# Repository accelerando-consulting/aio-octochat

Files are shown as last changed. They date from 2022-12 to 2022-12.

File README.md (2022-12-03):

# OctoChat - a tileable foot keyboard for people or pets

This project is a circuit board that allows one to construct a mechanical keyboard
as large or as small as you like.   From a single key, to potentially 64 keys.

The keyboard connects via I2C - it can connect direct to a raspberry pi, or to a small
microcontroller.   ESP32, ESP8266 and Nordic NRF52 are good choices.  

If you have a board that runs circuitpython such as the Adafruit feather or one of Accelerando's
Redsoil or Hailstone boards you can create a USB or Bluetooth keyboard with the included CircuitPython code.

Accelerando's Stacx project (for the Ardiuino framework) also supports these keys.

## How it works

The PCF8574 IO expander is used.   This chip has 8 pins, each key uses two pins.    A four key board can be made with
one octochat fitted with a PCF8574 and three more octochats *with no chip*.   Each active octochat can control three other passive octochats.   Connections can be chained, so you can add another active octochat into your board.   The PCF8574 supports 16 addresses, so you can have up to 16 active keys, plus up to 48 passive keys.

Each key has one keyswith and one LED.  Program the IO Expander's register with bit pattern 0xFF.   When a key is pressed, that bit will read zero.   To light a LED, program the corresponding bit to a zero.

The outputs of the PCF8574 are arranged thusly

 * D0 - the key on this module (pulled high, low when pressed)
 * D1 - the LED on this module (sink mode, program output low to light the LED)
 * D2 - the key on passive module 2
 * D3 - the LED on passive module 2
 * D4 - the key on passive module 3
 * D5 - the LED on passive module 3
 * D6 - the key on passive module 4
 * D7 - the LED on passive module 4

Each module has two connectors for each passive module, one at 90 degrees and one at 45 degrees.   You should use one or the other, not both.    All the ribbon connectors also relay the I2C SCL and SDA lines, so you can site a new active module anywhere you choose.

## What can I do with it

Make a soundboard for your cat, or dog.

Add foot controls to your PC.

Create assistive tech for the disabled.

Control machinery (I use one to control vacuum pickup and fume extraction at my soldering station).

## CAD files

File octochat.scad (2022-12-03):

/* [Parameters] */

item="base"; // ["base","key","button","mat","mat2d", "assembly"]
dia=58;
outer_height=15;
pcb_height=3;
pcb_rim = 3.5;

button_stride = 105;

/* [Keyswitch] */

key_type="cherry"; //["cherry","kailh"]
kailh_key_height=5.5;
kailh_key_stroke=3;
cherry_key_height=11;
cherry_key_stroke=4;

/* [Advanced] */

pcb_thickness=1.6;
show_pcb=false;
invert=true;
key_clearance=1.2;

i2c_height=5-pcb_thickness;
i2c_width = 7;

fpc_width =10;
fpc_height=0;
fpc_thickness=pcb_height-0.5;

/* [Hidden] */

$fn=60;
fuz=0.1;fuzz=2*fuz;


// A regular octogon is cylinder($fn=8) but KiCad doesn't do regular polygons so an APPROXIMATE octogon is drawn

module bogoctogon20() {
    translate([-25,-25])
	polygon(points=[[15,0],[35,0],[50,15],[50,35],[35,50],[15,50],[0,35],[0,15]]);
}

module bogoctogon(side) {
    scale([side/20,side/20])
	translate([-25,-25])
	polygon(points=[[15,0],[35,0],[50,15],[50,35],[35,50],[15,50],[0,35],[0,15]]);
}

module bogoctoprism(side,height) {
    linear_extrude(height=height) { bogoctogon(side); }
}

module roundover(l=20,r=5) {
    difference() {
	cube([r,r,l]);
	translate([0,0,-fuz]) cylinder(r=r,h=l+fuzz);
    }
}

module tube(d,h,wall=5) {
    difference() {
	cylinder(d=d,h=h);
	translate([0,0,-fuz])cylinder(d=d-2*wall,h=h+fuzz);
    }
}

module bogoctobutton(side,height,radius) {
    difference() {
	bogoctoprism(side,height);
	for (i=[0:7]) {
	    //color("red") rotate([0,0,i*360/8]) translate([side*1.25,0,height]) rotate([90,0,0]) translate([0,0,-side*0.6]) cylinder(r=radius,h=side*1.2);
	    color("green") rotate([0,0,i*360/8]) translate([side*1.25-radius,0,height-radius]) rotate([90,0,0]) translate([0,0,-side*0.6]) roundover(l=side*1.2,r=radius);
	}
    }
}

//bogoctoprism(20,5);

module cylinder_roundover(d=20,r=5) {
    rotate_extrude() {
	translate([d/2-r,0,0]) {
	    difference() {
		square([r,r]);
		circle(r=r);
	    }
	}
    }
}

module bollard(d,h,r=5,n=0) {
    difference() {
	if (n) {
	    rotate([0,0,1.5*(360/n)]) cylinder(d=d,h=h,$fn=n);
	}
	else {
	    cylinder(d=d,h=h);
	}
	translate([0,0,h-r]) cylinder_roundover(d=d,r=r);
    }
    //color("red") translate([0,0,h-r]) cylinder_roundover(d=d,r=r);
}


module drills(h=30,d=1.6) {
    for (i=[0:7]) {
	rotate([0,0,(i+0.5)*360/8]) translate([24.4,0,0]) cylinder(d=d,h=h);
    }
}

module fpc_slots() {
    for (i=[0:7]) {
	rotate([0,0,i*360/8]) translate([dia/2,0,fpc_height+fpc_thickness/2]) cube([20,fpc_width,fpc_thickness],center=true);
    }
}

module fpc_clearance() {
    for (i=[0:7]) {
	rotate([0,0,i*360/8]) translate([dia/2,0,fpc_height+fpc_thickness/2]) cube([20,fpc_width,fpc_thickness],center=true);
    }
}

module pcb() {
    color("green",0.5) bogoctoprism(20.5,pcb_thickness);
}

module base(pcb=false) {
    difference() {
	//color("yellow", 0.6) cylinder(d=dia,h=outer_height);
	bollard(d=dia,h=outer_height,r=3,n=8);
	tube(d=dia,h=outer_height,wall=0.5);
	translate([0,0,-fuz]) {
	    bogoctoprism(20.5,pcb_height+pcb_thickness);
	    bogoctoprism(20.5-pcb_rim,outer_height+fuzz);
	    drills(h=pcb_height+8,d=1.6);
	    fpc_slots();
	    translate([dia/2,0,pcb_height+pcb_thickness+i2c_height/2]) cube([20,i2c_width,i2c_height],center=true);
	}
    }
    if (pcb) {
	translate([0,0,pcb_height]) {
	    %pcb();
	    translate([0,0,pcb_thickness]) %keyswitch();
	}
    }
}


module post(l,w,h) {
    translate([-l/2,-w/2,0]) cube([l,w,h]);
}

module rounded_post(l,w,h,r=2) {
    translate([-l/2,-w/2,0]) {
	minkowski() {
	    cube([l,w,h]);
	    cylinder(r=r,h=1);
	}
    }
}

module kailh_keycap_pins() {
    translate([-3.5,-1.5,0]) cube([1,2.5,3]);
    translate([3.5-1.2,-1.5,0]) cube([1,2.5,3]);
}


module cherry_keycap_cross(h=4) {
    cube([4+2*fuz,1.3+2*fuz,h], center=true);
    cube([1.1+2*fuz,4+2*fuz,h], center=true);
}


module keypost(h) {
    post(10,5,h);
    translate([0,0,h]) kailh_keycap_pins();
}

module cherry_keypost(h) {
    difference() {
	post(6,4,h);
	translate([0,0,h]) cherry_keycap_cross(h=10);
    }		      
}

module kailh_keyswitch() {
}

module cherry_keyswitch() {
    translate([0,0,11/2]) color("white",0.5) cube([15.6,15.6,11],center=true);
    translate([0,0,11+2]) color("red",0.5) cherry_keycap_cross();
}

module keyswitch() {
    if (key_type=="cherry") cherry_keyswitch();
    if (key_type=="kailh") kailh_keyswitch();
}

module kailh_button() {
    button_height = outer_height+10-pcb_height;
    difference() {
	bogoctobutton(20.5-pcb_rim-key_clearance,button_height,3);
	translate([0,0,-fuz]) bogoctobutton(19.5-pcb_rim-key_clearance,button_height-1,2);
    }
    keycap_height = button_height-key_height;
    translate([0,0,button_height]) scale([1,1,-1]) keypost(keycap_height);
}

module cherry_button() {
    button_height = outer_height-pcb_height;
    difference() {
	bogoctobutton(20.5-pcb_rim-key_clearance,button_height,3);
	translate([0,0,-fuz]) bogoctobutton(19.3-pcb_rim-key_clearance,button_height-1.2,2);
    }
    keycap_height = button_height-cherry_key_height+cherry_key_stroke;
    translate([0,0,button_height]) scale([1,1,-1]) cherry_keypost(keycap_height);
}

module button() {
    if (key_type=="cherry") cherry_button();
    if (key_type=="kailh") kailh_button();
}

module kailh_button_assembly() {
    base(show_pcb);
    translate([0,0,pcb_height+pcb_thickness+kailh_key_stroke]) kailh_button();
}
module cherry_button_assembly() {
    base(show_pcb);
    translate([0,0,pcb_height+pcb_thickness+cherry_key_stroke+0]) cherry_button();
}

module button_assembly() {
    if (key_type=="cherry") cherry_button_assembly();
    if (key_type=="kailh") kailh_button_assembly();
}

module button_set() {
    translate([0,-button_stride/2,-fuz]) children();
    translate([button_stride,-button_stride/2,-fuz]) children();
    translate([-button_stride,-button_stride/2,-fuz]) children();
    translate([0,button_stride /2,-fuz]) children();
}

module mat(buttons=false) {
    difference() {
	translate([0,0,6]) cube([3*button_stride,2*button_stride,12],center=true);
	button_set() bollard(d=dia,h=outer_height,r=5,n=8);
    }
    if (buttons) button_set() button_assembly();
}

/*
  scale([1,1,-1]) {
  intersection() {
  base();
  cylinder(d=dia,h=pcb_height+1);
  }
  translate([0,0,pcb_height]) intersection() {
  button();
  cylinder(d=dia,h=1);
  }
  }
*/


//keypost(4);

//mat();


//bollard(d=50,h=100,r=5);

difference() {
    //rotate([0,invert?180:0,0])
    union() {
	if (item=="base") translate([0,0,invert?outer_height:0]) rotate([0,invert?180:0,0]) base(show_pcb/*&&!invert*/);
	if (item=="key") translate([0,0,invert?(outer_height-pcb_height):0]) rotate([0,invert?180:0,0]) /*translate([0,0,pcb_height])*/ cherry_button();
	if (item=="mat") mat();
	if (item=="mat2d") projection() mat();
	if (item=="button") button_assembly();
	if (item=="assembly") mat(buttons=true);
    }
    //translate([-50,-50,0]) cube([100,50,50]);
}

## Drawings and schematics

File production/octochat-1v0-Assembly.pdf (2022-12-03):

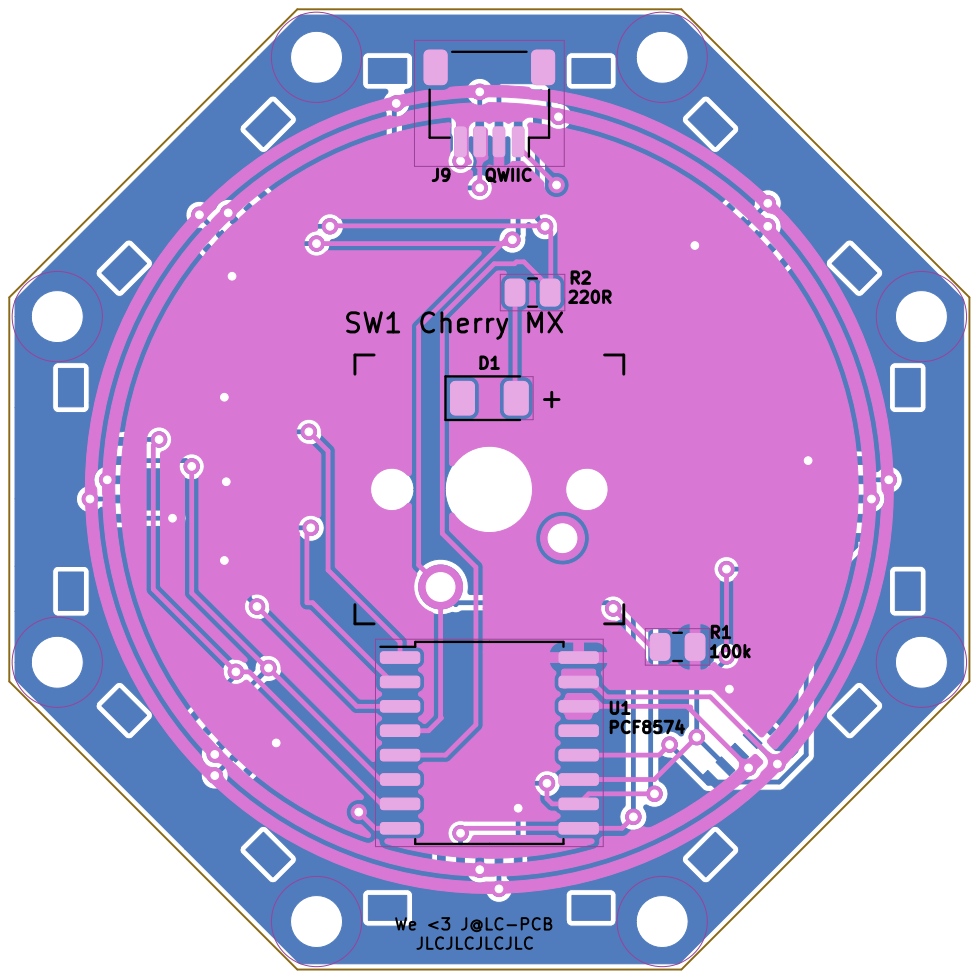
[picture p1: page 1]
JLCJLCJLCJLC; QWIIC

U1PCF8574 R2
We <3 J@LC-PCB SW1 Cherry MX

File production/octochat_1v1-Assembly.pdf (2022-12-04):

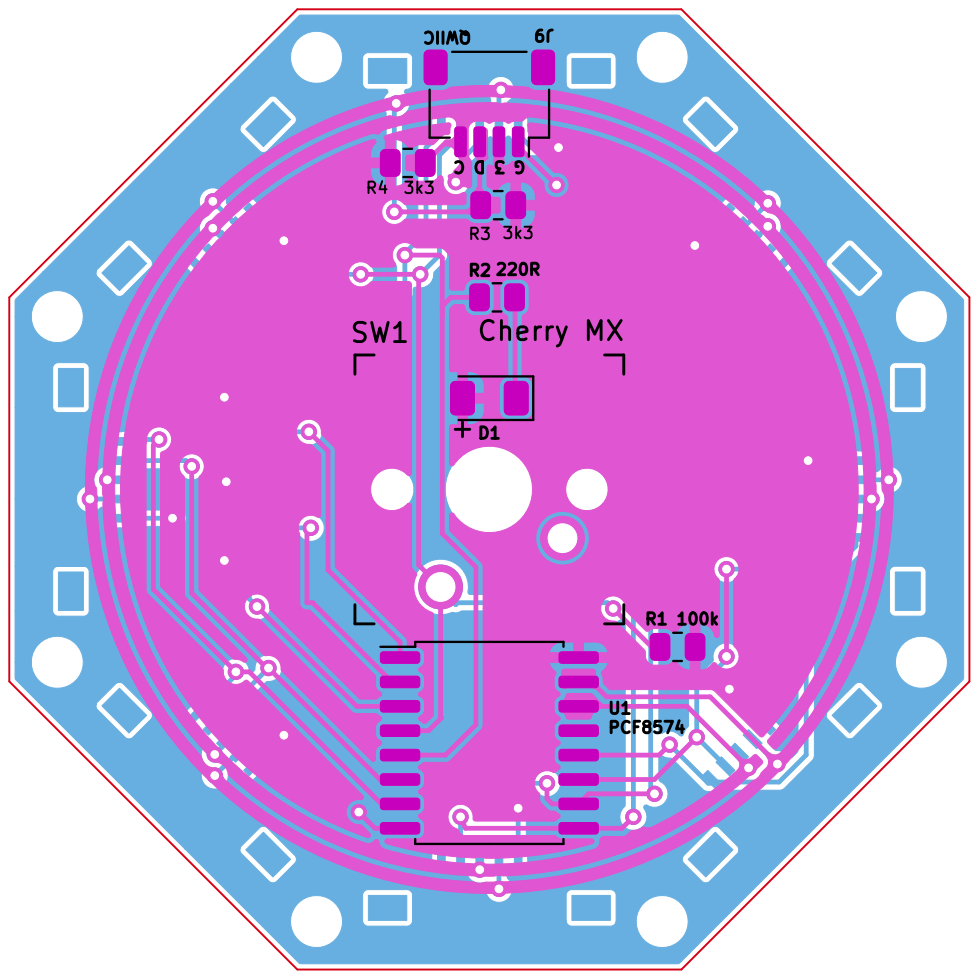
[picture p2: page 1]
U1PCF8574 R4; R1 100k D1 QWIIC

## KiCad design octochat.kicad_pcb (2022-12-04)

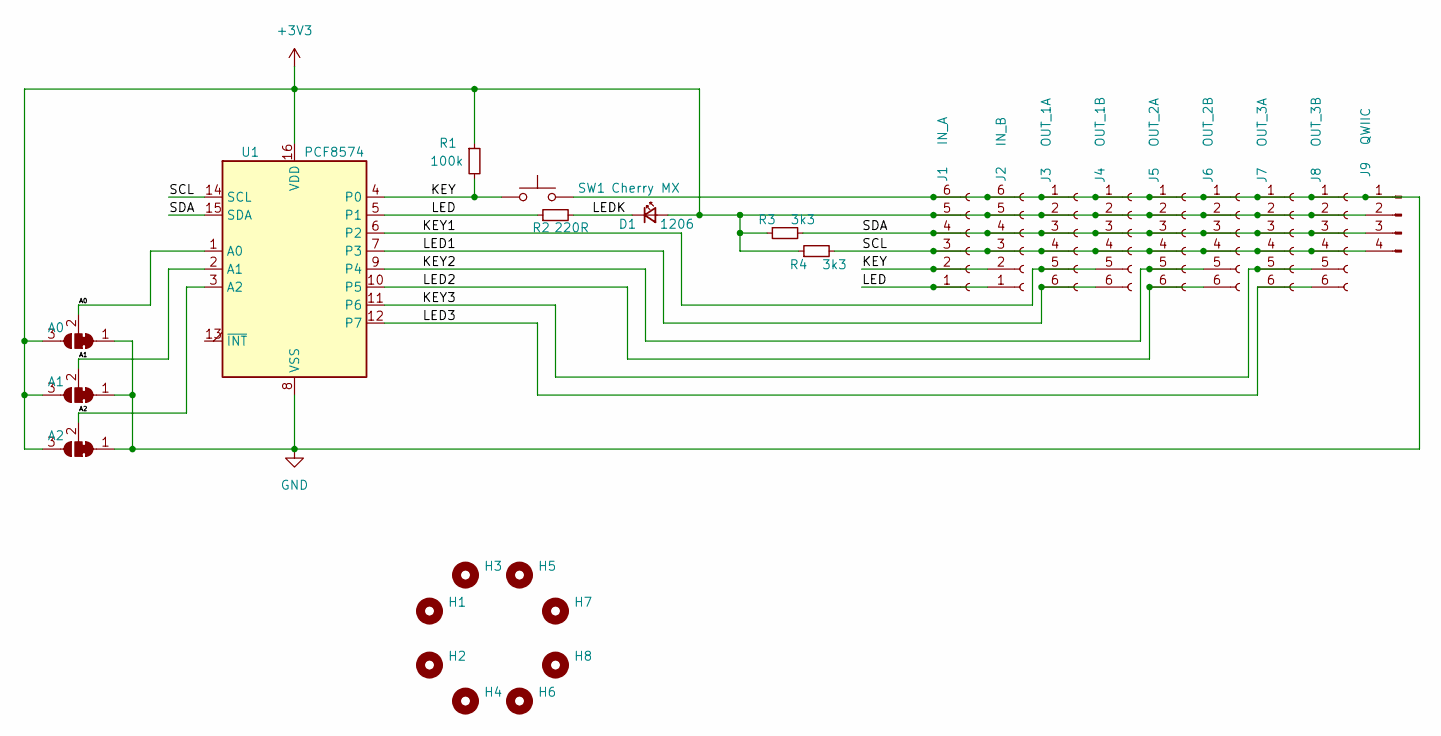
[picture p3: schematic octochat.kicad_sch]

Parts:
D1: 1206; LED_1206_3216Metric
H1, H2, H3, H4, H5, H6, H7, H8: MountingHole; MountingHole_2.1mm
J1: IN_A; Molex_200528-0060_1x06-1MP_P1.00mm_Horizontal
J2: IN_B; Molex_200528-0060_1x06-1MP_P1.00mm_Horizontal
J3: OUT_1A; Molex_200528-0060_1x06-1MP_P1.00mm_Horizontal
J4: OUT_1B; Molex_200528-0060_1x06-1MP_P1.00mm_Horizontal
J5: OUT_2A; Molex_200528-0060_1x06-1MP_P1.00mm_Horizontal
J6: OUT_2B; Molex_200528-0060_1x06-1MP_P1.00mm_Horizontal
J7: OUT_3A; Molex_200528-0060_1x06-1MP_P1.00mm_Horizontal
J8: OUT_3B; Molex_200528-0060_1x06-1MP_P1.00mm_Horizontal
J9: QWIIC; JST_SH_SM04B-SRSS-TB_1x04-1MP_P1.00mm_Horizontal
JP1: A0; SolderJumper-3_P1.3mm_Bridged12_RoundedPad1.0x1.5mm
JP2: A1; SolderJumper-3_P1.3mm_Bridged12_RoundedPad1.0x1.5mm
JP3: A2; SolderJumper-3_P1.3mm_Bridged12_RoundedPad1.0x1.5mm
R1: 100k; R_0805_2012Metric
R2: 220R; R_0805_2012Metric
R3, R4: 3k3; R_0805_2012Metric
SW1: Cherry MX; SW_MX
U1: PCF8574; SOIC-16W_7.5x10.3mm_P1.27mm

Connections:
+3V3: D1.2 (A), J1.5, J2.5, J3.2, J4.2, J5.2, J6.2, J7.2, J8.2, J9.2, JP1.3 (B), JP2.3 (B), JP3.3 (B), R1.1, R3.1, R4.1, U1.16 (VDD)
/A0: JP1.2 (C), U1.1 (A0)
/A1: JP2.2 (C), U1.2 (A1)
/A2: JP3.2 (C), U1.3 (A2)
/KEY: J1.2, J2.2, R1.2, SW1.1, U1.4 (P0)
/KEY1: J3.5, J4.5, U1.6 (P2)
/KEY2: J5.5, J6.5, U1.9 (P4)
/KEY3: J7.5, J8.5, U1.11 (P6)
/LED: J1.1, J2.1, R2.1, U1.5 (P1)
/LED1: J3.6, J4.6, U1.7 (P3)
/LED2: J5.6, J6.6, U1.10 (P5)
/LED3: J7.6, J8.6, U1.12 (P7)
/LEDK: D1.1 (K), R2.2
/SCL: J1.3, J2.3, J3.4, J4.4, J5.4, J6.4, J7.4, J8.4, J9.4, R4.2, U1.14 (SCL)
/SDA: J1.4, J2.4, J3.3, J4.3, J5.3, J6.3, J7.3, J8.3, J9.3, R3.2, U1.15 (SDA)
GND: J1.6, J2.6, J3.1, J4.1, J5.1, J6.1, J7.1, J8.1, J9.1, JP1.1 (A), JP2.1 (A), JP3.1 (A), SW1.2, U1.8 (VSS)

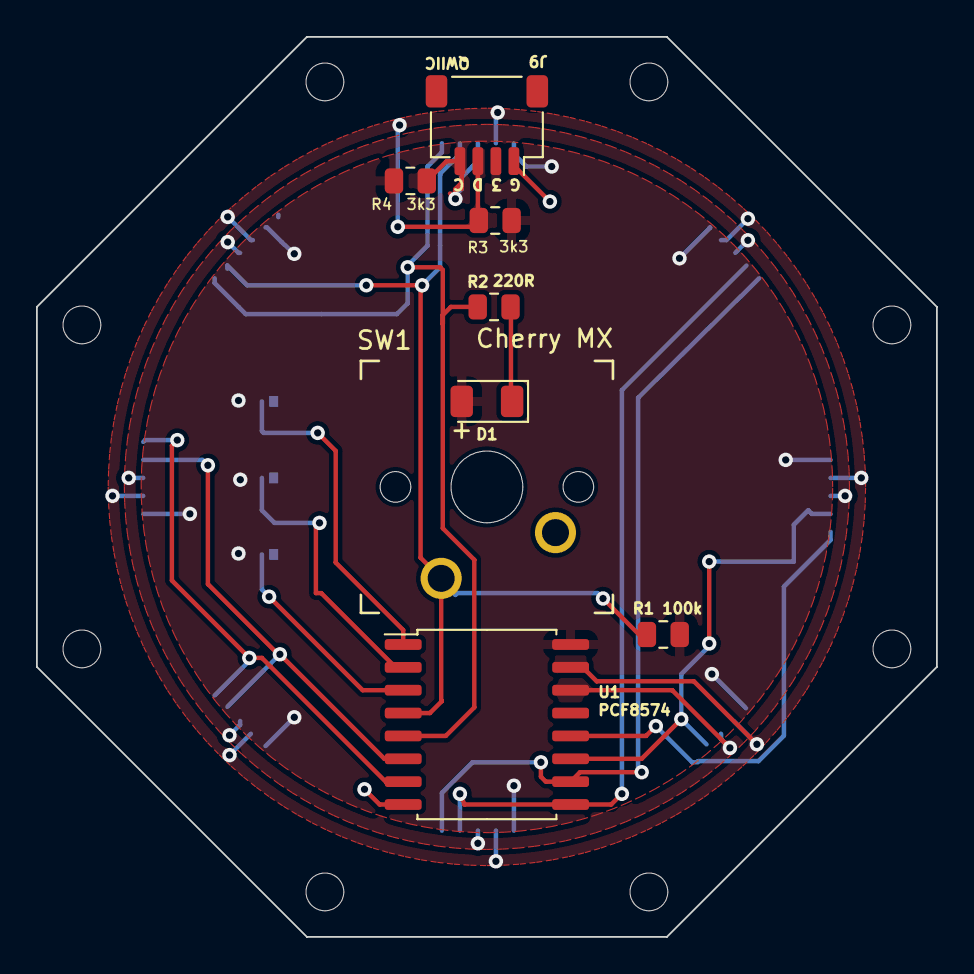
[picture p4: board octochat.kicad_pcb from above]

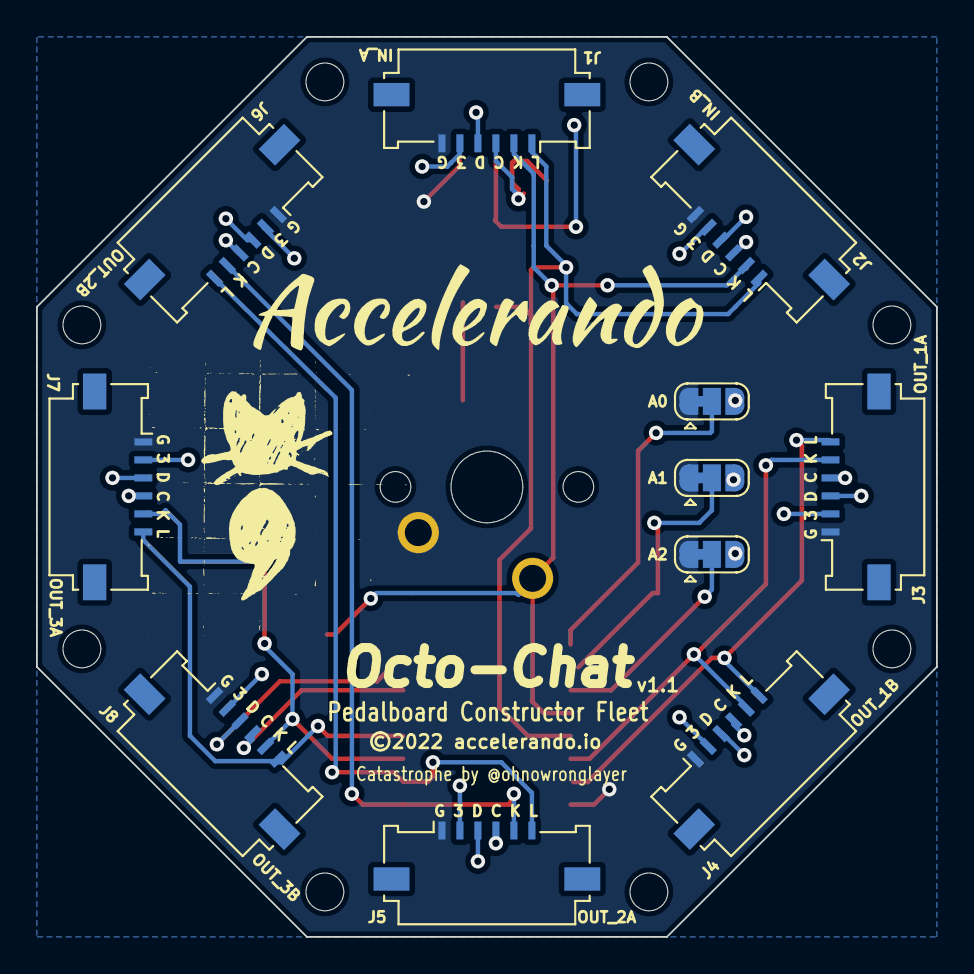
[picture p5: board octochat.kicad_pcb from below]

Board: 2 copper layers, 50.0 x 50.0 mm, 27 parts (11 on the bottom side), 16 nets.

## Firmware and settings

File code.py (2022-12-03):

print("Jello World!")

import time

import board
import usb_hid
from adafruit_hid.keyboard import Keyboard
from adafruit_hid.keycode import Keycode

print("scanning i2c")
i2c = board.I2C()

while not i2c.try_lock():
    pass
i2c_addrs = i2c.scan()
i2c.unlock()

i2c_sensors = []
for addr in i2c_addrs:
    if addr < 32: continue
    print("I2C device found at:",hex(addr))
    i2c_sensors.append({
        'addr': addr,
        #'device': adafruit_pcf8574.PCF8574(i2c_bus=i2c, addrress=addr),
        'state': 0,
    })
print("Sensor table is ", i2c_sensors)

print("creating keyboard")
kbd = Keyboard(usb_hid.devices)

def read_sensor(addr, bus=i2c):
    regs = bytearray(1)
    bus.readfrom_into(address=addr, buffer=regs)
    return regs[0]

def write_sensor(addr, value, bus=i2c):
    print("write_sensor({}, {})".format(hex(addr), hex(value)))
    regs = bytearray(1)
    regs[0] = value
    while not bus.try_lock():
        pass
    bus.writeto(addr, regs)
    bus.unlock()
    

def poll_sensors(bus=i2c, sensors=i2c_sensors):

    #print("lock bus", bus)
    while not bus.try_lock():
        pass
    
    for s in sensors:
        #print("poll sensor", s)
        b = read_sensor(s['addr'])
        if (b != s['state']):
            s['state']=b
            print("Device at {} has new state {}".format(s['addr'], hex(s['state'])))
                
    #print("release bus", bus)
    bus.unlock()

key_table = [
    [56, 0, False, Keycode.UP_ARROW],
]

def get_sensor(addr, sensors=i2c_sensors):
    for s in sensors:
        if s["addr"]==addr:
            return s
    return None

def is_pressed(bits, pos):
    return ((bits & (1<<(pos*2)))==0)

def scan_keys(bus=i2c, sensors=i2c_sensors, keys=key_table):
    for k in keys:
        (addr, pos ,pressed, code) = k
        #print("Examine key addr={} pos={} pressed={} code={}".format(addr,pos,pressed,code))
        s = get_sensor(addr)
        if s==None: continue
        state = s['state']
        
        if not pressed and is_pressed(state, pos):
            # press detected, light up the led and send a keystroke
            print("Keypress detected state=",hex(state))
            s['state'] &= ~(1<<(1+pos*2)) # led low (sinking current)
            s['state'] |= (1<<(0+pos*2)) # key high (input pullup)
            write_sensor(addr, s['state'])
            kbd.send(code)
            k[2]=True # pressed
        elif pressed and not is_pressed(state, pos):
            # release detected, turn off the LED
            print("Release detected state=",hex(state))
            s['state'] |= (1<<(1+pos*2)) # led high (not sinking current)
            s['state'] |= (1<<(0+pos*2)) # key high (input pullup)
            write_sensor(addr, s['state'])
            k[2]=False # released


print("scan loop")
while True:
    poll_sensors()
    scan_keys()
    time.sleep(0.1)
    

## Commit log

2022-12-03 Octochat 1v1 - multi node mechanical footboard
    [octochat.kicad_pcb, octochat.kicad_sch, octochat.scad]
2022-12-03 Gerbers for octochat 1v1
    [octochat.kicad_pcb]
2022-12-04 Add BOM and assembly diagram
    [octochat.kicad_pcb]

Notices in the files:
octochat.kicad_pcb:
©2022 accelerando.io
